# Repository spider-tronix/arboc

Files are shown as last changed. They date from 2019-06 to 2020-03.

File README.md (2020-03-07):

# Arboc
# Abstract:

Researches about underwater propulsion mainly illustrate the use of propellers or thrusters to propel a robot in an underwater environment whereas most of the aquatic animals change their body shape in order to navigate.The shape-change generating propulsion force makes them move forward or backward effectively.The underwater snake-like robot is a kind of bionic robot which changes its body shape to navigate in underwater environment.The aim of the project is to understand the dynamics of underwater robots in general and the effect of lift, drag and hydrodynamic coefficients on them and to simulate, validate and develop a snake-like robot which is robust enough to carry out underwater exploratory tasks.

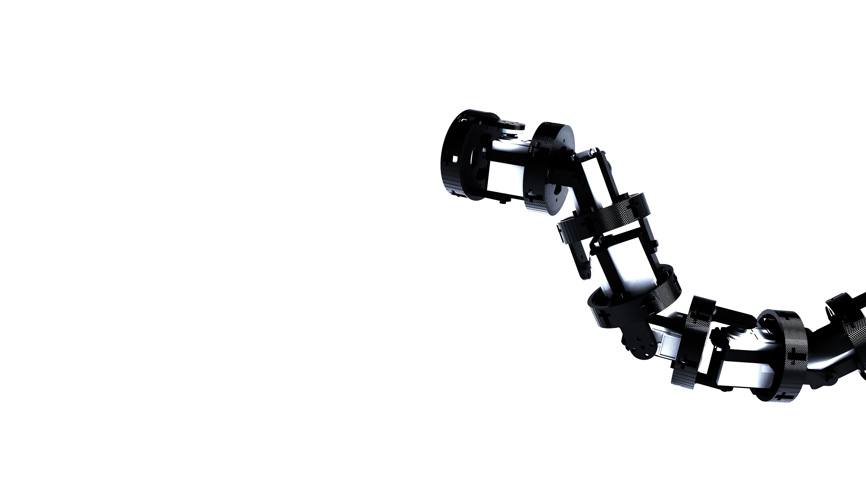
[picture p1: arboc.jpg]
arboc


# Scope of research ::

arboc

  •	Comprehensive simulation and validation of underwater bionic robots using ROS and gazebo.

  •	Goal based locomotion and object tracking for underwater exploratory robots using deep reinforcement learning.

# Paper Submission:
  •	ICCAR
  
# Team:

  • Aditya Singh [https://github.com/adityasingh3007]
  
  • Jack Samuel S [https://github.com/jaxxstar] 
  
  • Manu Aatitya [https://github.com/manuaatitya]  
  
  • Senthur Raj [https://github.com/imsenthur]

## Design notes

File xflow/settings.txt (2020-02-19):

Project Tree:

Create geometry:
__Direction: x:0.0 y:0.0 z:1.0
__Num radial segments: 20
__Num longit. segments: 16

Environment:
__Engine:
____Kernel: 2d

__Environment:
____Wind tunnel*: Dimensions: ()m
____Boundary conditions: Velocity: X: ()m.s-1

Materials:
(For a cylinder of diameter* 0.4m)

__Materials: Material 1
____Reference density*: 1kg.m-3
____Dynamic viscosity*: 0.001Pa.s
____Reynolds number*: 4000
____Velocity of fluid: 10m.s-1

Simulation:
__Time:
____Simulation time: 2s
__Resolution:
____Resolved scale: 0.04m

------------------------------------
------------- R U N ----------------
------------------------------------

Post processing:

Refinement method:
__Adaptive refinement:
____Target resolved resolution*: 0.02m
____Wake resolution*: 0.02m

*Subjected to change

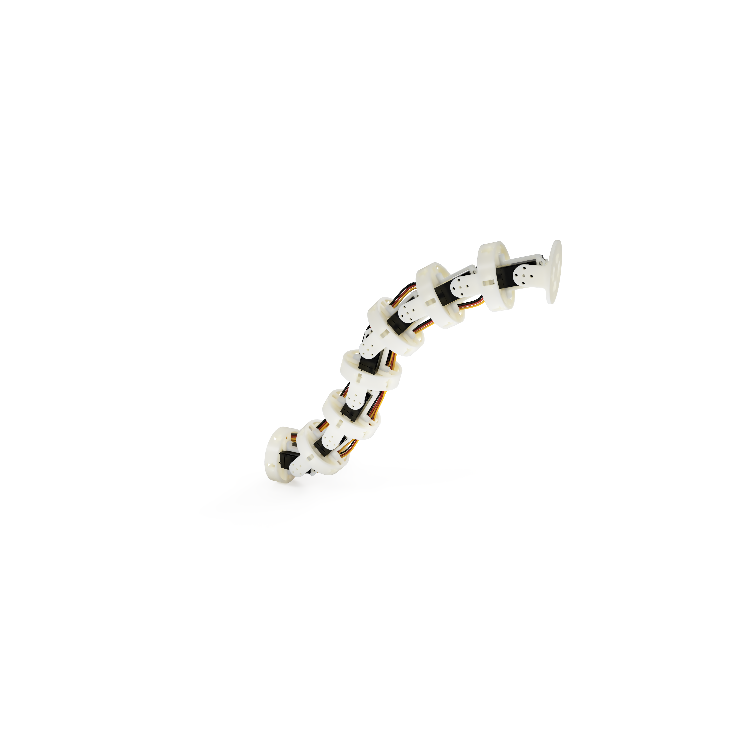
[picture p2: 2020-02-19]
design/Render/iso.png

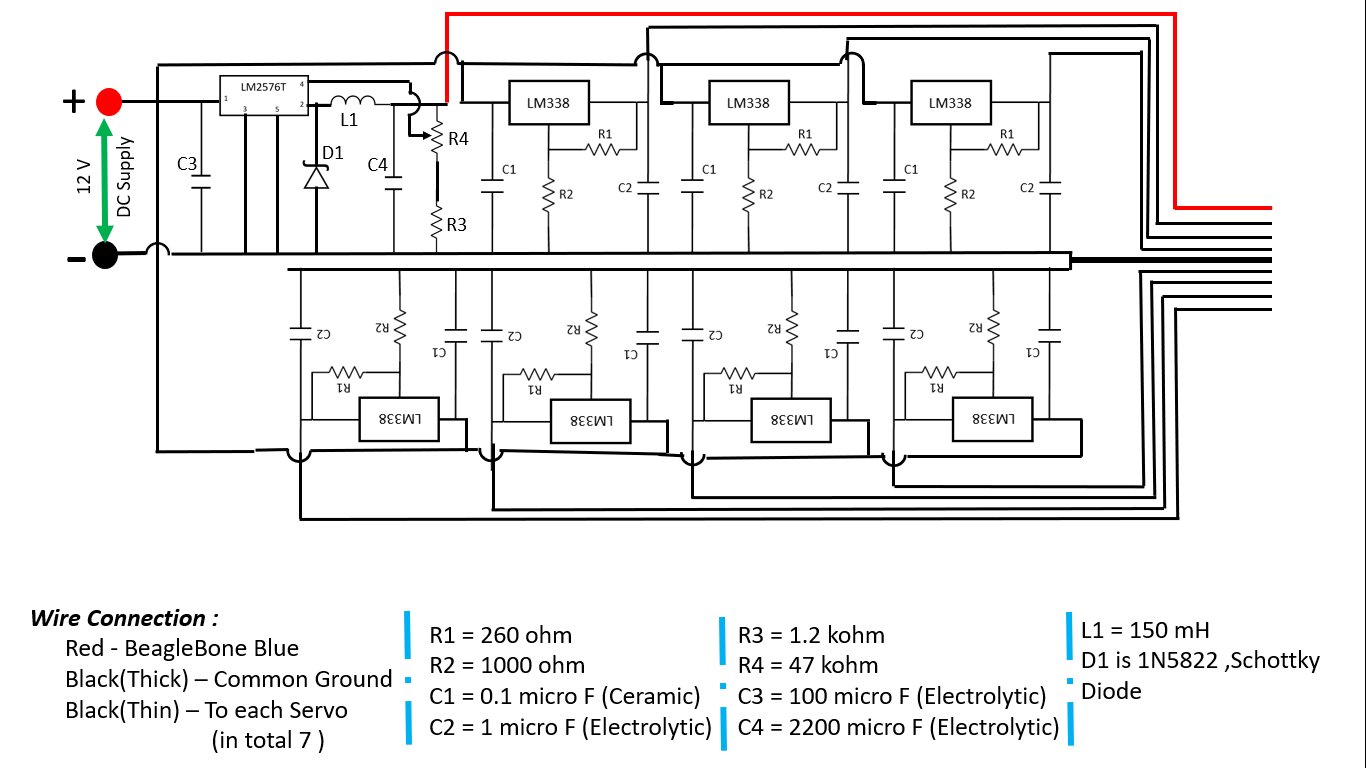
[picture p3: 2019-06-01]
powerSupplyDesign/circuit.png

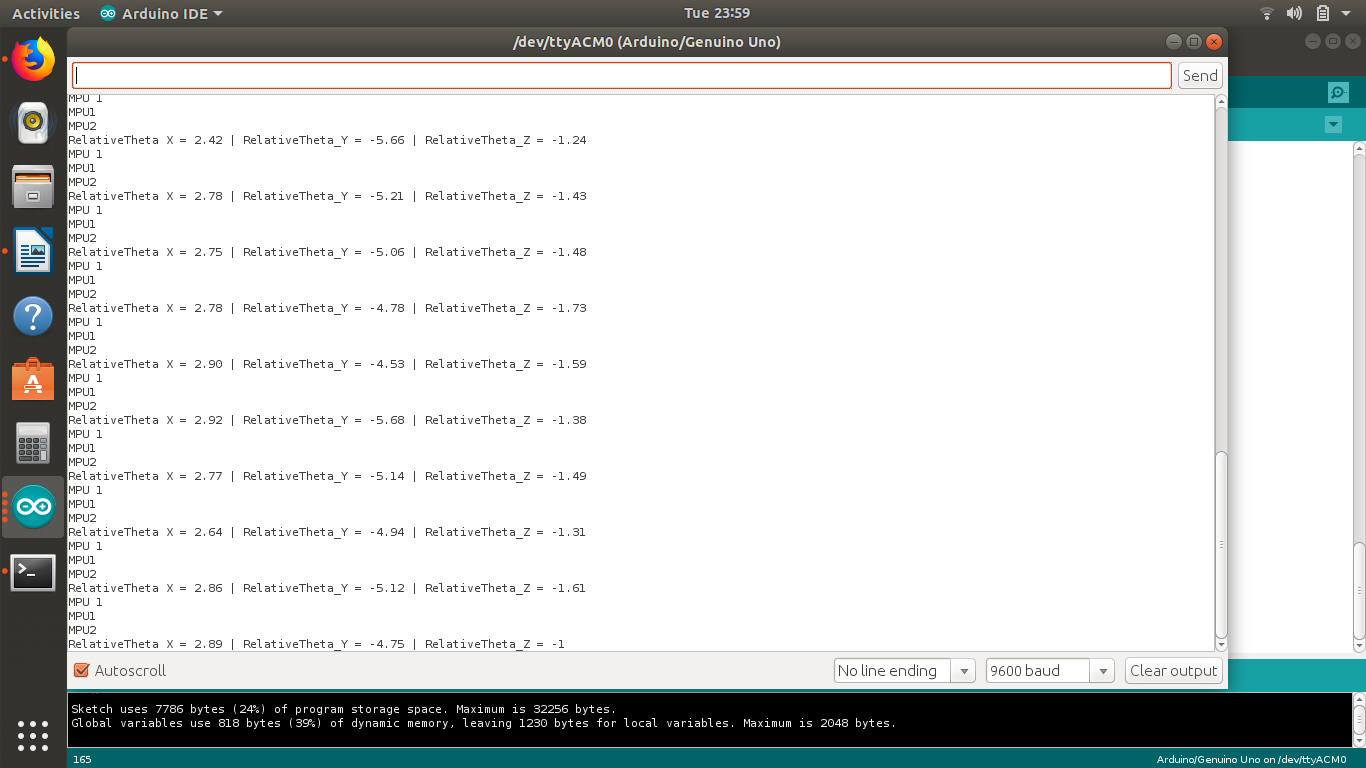
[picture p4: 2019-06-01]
control/IMU/Relative_angle.png

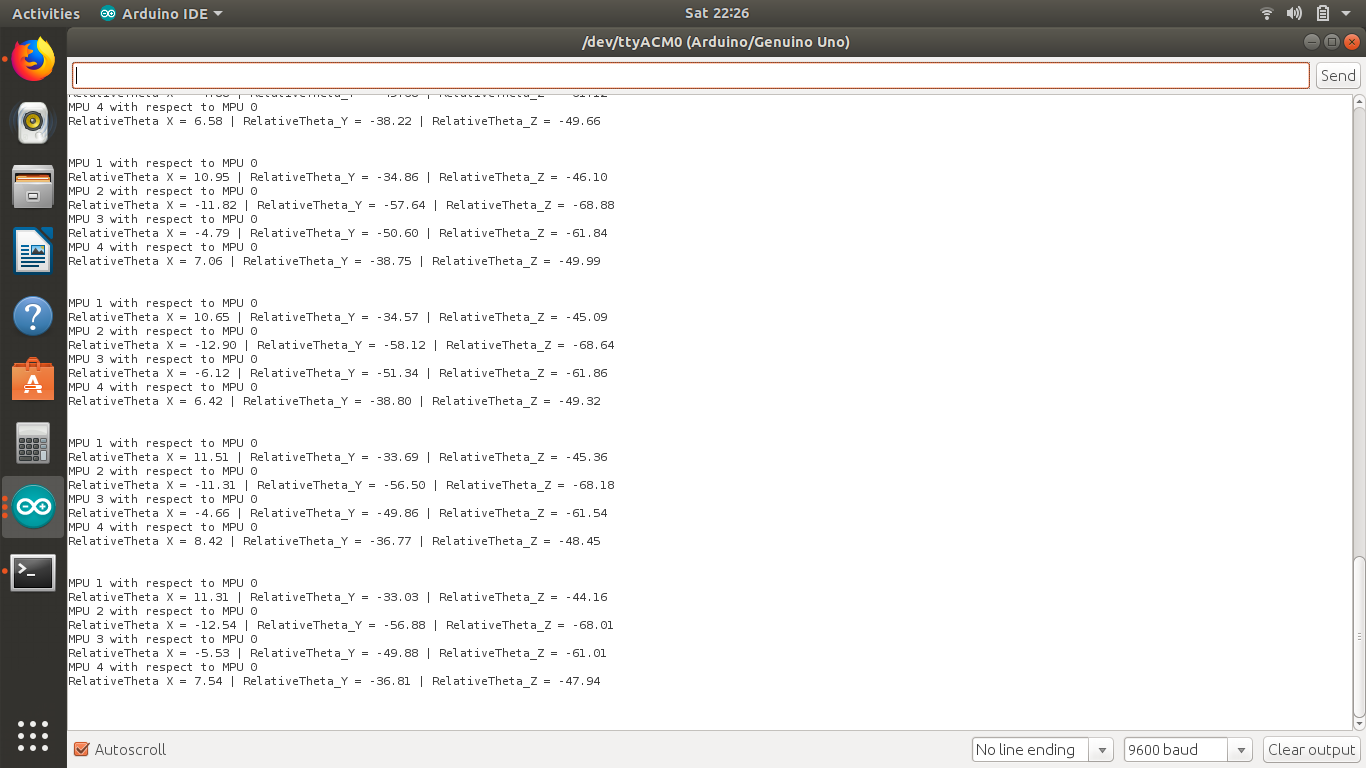
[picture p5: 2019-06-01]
control/IMU/relative_angle_5imu.png

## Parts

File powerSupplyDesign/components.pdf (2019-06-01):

LIST OF CIRCUIT ELEMENTS

S No. | Name | Range / Value | Qty
1. | LM338T Voltage Regulator (TO-220) | 1.2V to 32V, 5A | 10
2. | LM2576T Adj Regulator (TO-220) | | 03
3. | Resistor | 220 ohm,¼ watt 1 kohm,¼ watt 1.2 kohm,¼ watt | 10 10 03
4. | Rheostat | 47 kohm,¼ watt | 02
5. | Capacitor (Electrolytic) | 1 uF, 20 V 100 uF, 30 V 2200 uF, 20 V | 10 03 03
6. | Capacitor (Ceramic) | 0.1 uF, 30V | 10
7. | Inductor (CD74R) | 150 mH | 03
8. | Schottky Diode (1N5822) | 10-20V | 03
9. | Heat sinks | 1k/watt thermal resistance 30Watts disspation capacity | 10
10 | Thermal grease

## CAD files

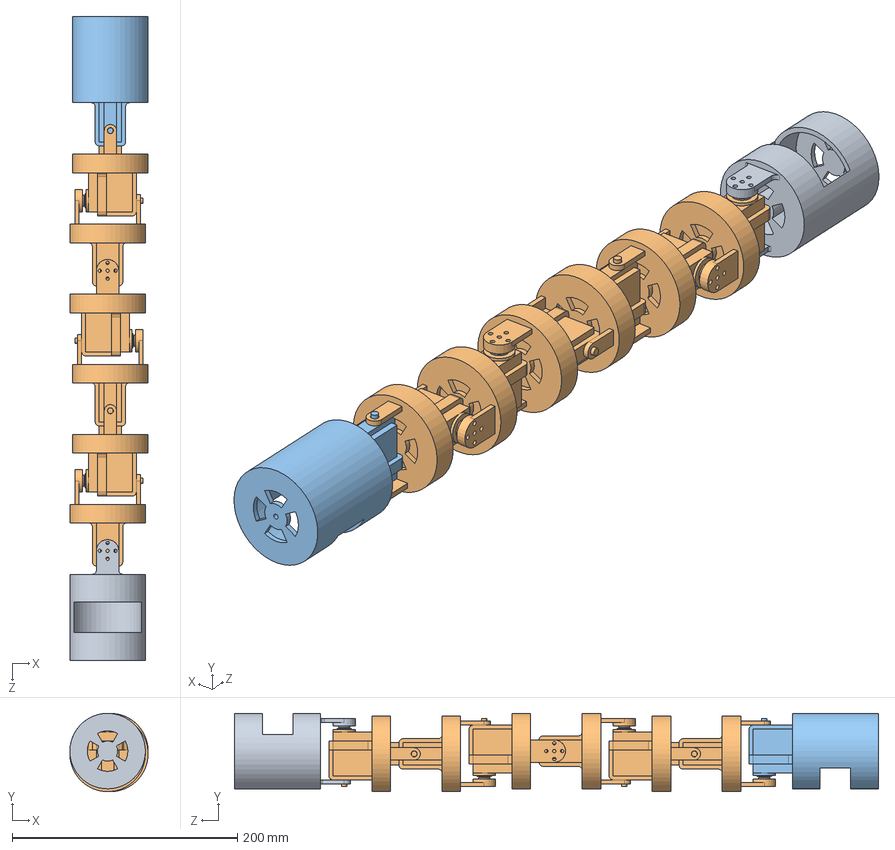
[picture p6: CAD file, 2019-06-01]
mechanicalDesign/solidworks/mainAssembly/arboc.SLDASM
69.5 x 69.5 x 571.3 mm
head
module x 6
tail

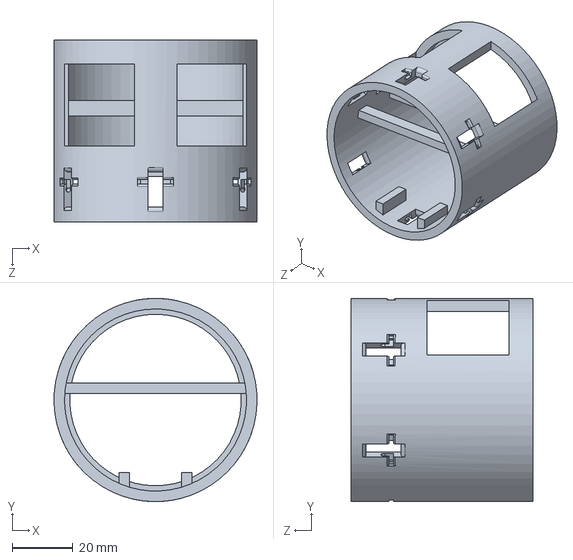
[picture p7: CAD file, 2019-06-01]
mechanicalDesign/solidworks/subAssembly/headNew.SLDASM
66.9 x 67.0 x 60.0 mm

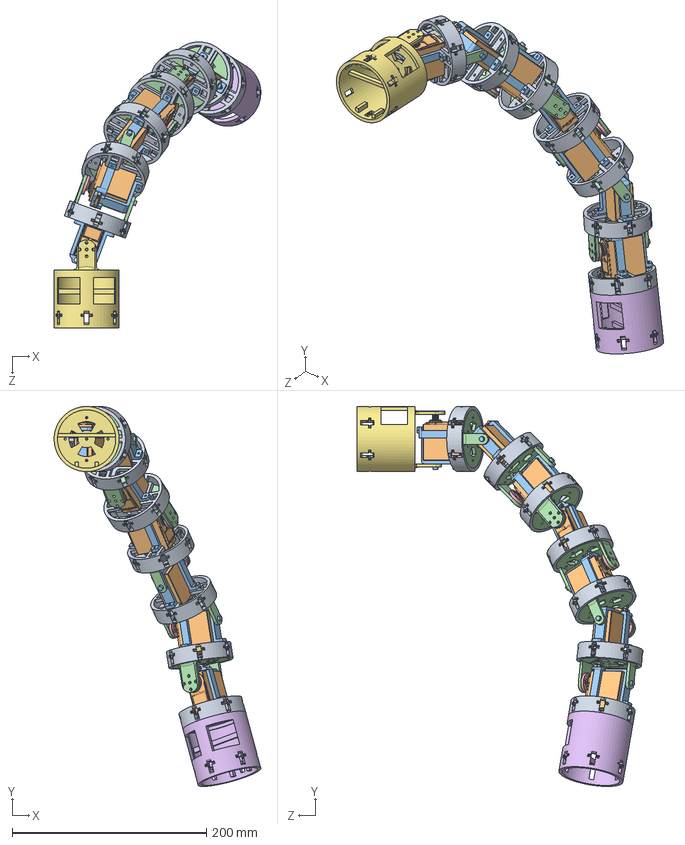
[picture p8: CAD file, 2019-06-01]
mechanicalDesign/solidworks/mainAssembly/arbocImprov.SLDASM
212.8 x 391.1 x 294.4 mm
LowerBracket x 7
Servo x 7
MiddleBracket x 7
UpperBracket x 6
Metalhorn x 6
Tail
Newhead

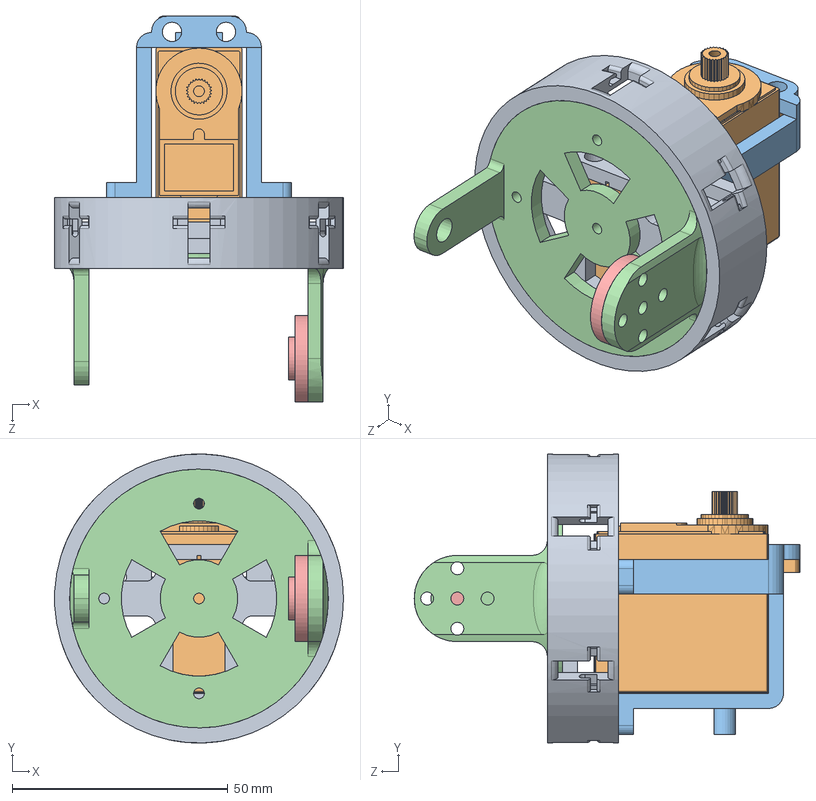
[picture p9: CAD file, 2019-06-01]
mechanicalDesign/solidworks/subAssembly/module.SLDASM
67.0 x 67.0 x 89.4 mm
LowerBracket
Servo
MiddleBracket
UpperBracket
Metalhorn

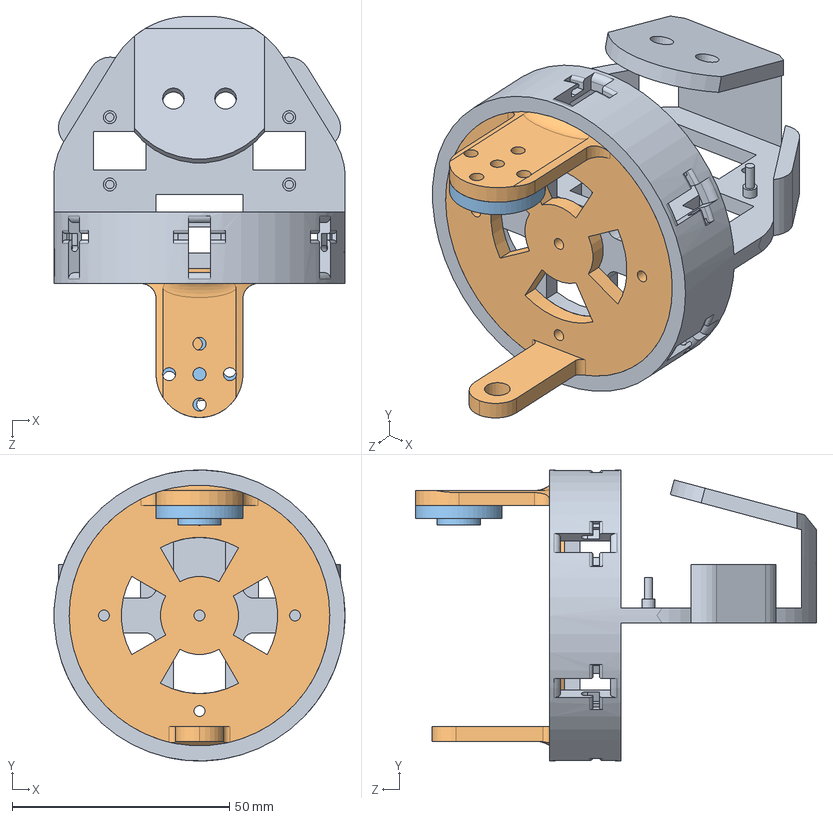
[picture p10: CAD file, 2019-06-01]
mechanicalDesign/solidworks/subAssembly/head.SLDASM
67.0 x 67.0 x 92.4 mm
Head
UpperBracket
Metalhorn

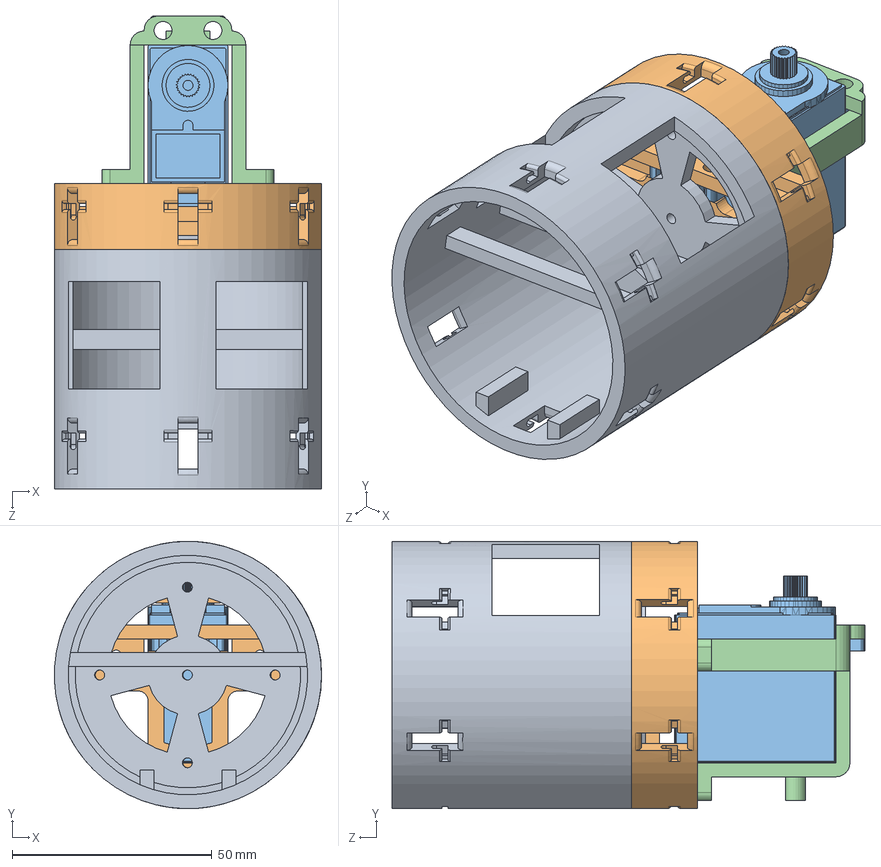
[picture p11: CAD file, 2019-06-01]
mechanicalDesign/solidworks/subAssembly/tail.SLDASM
67.0 x 67.0 x 118.5 mm
Tail
LowerBracket
Servo
MiddleBracket

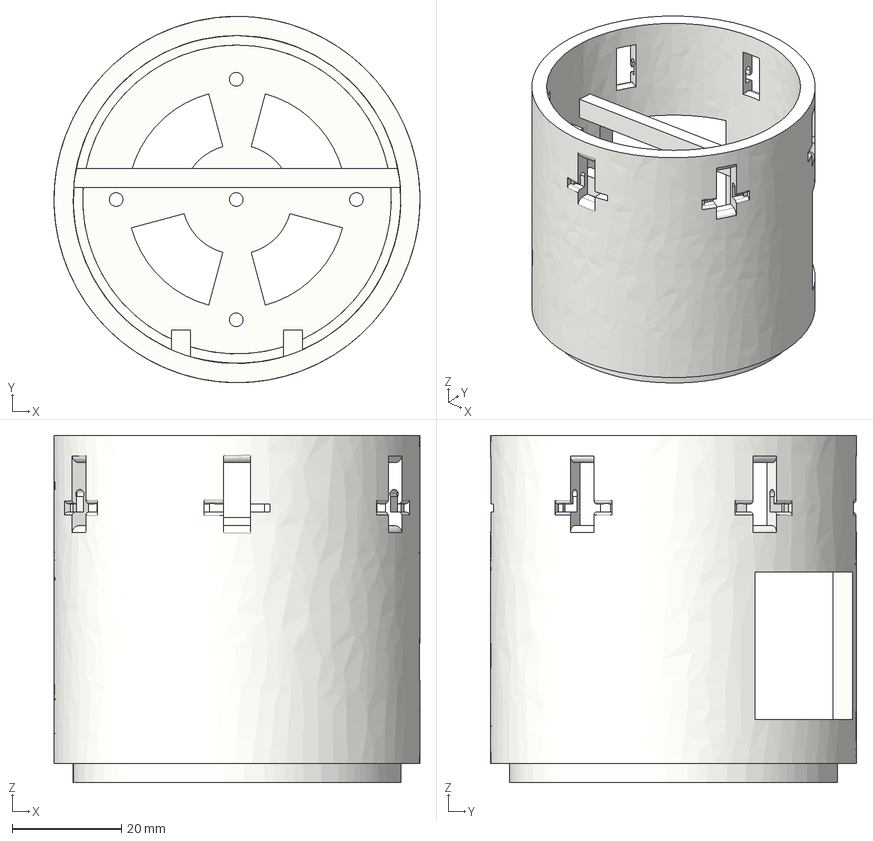
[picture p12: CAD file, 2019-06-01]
mechanicalDesign/3DprintedParts/type5.step
66.9 x 67.0 x 63.5 mm

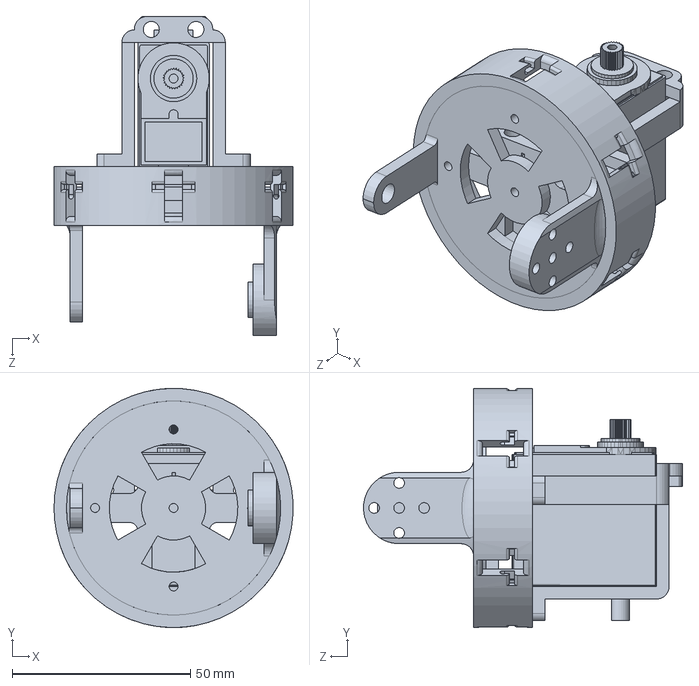
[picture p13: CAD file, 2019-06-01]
mechanicalDesign/solidworks/iges/link.SLDPRT
67.0 x 67.0 x 89.4 mm

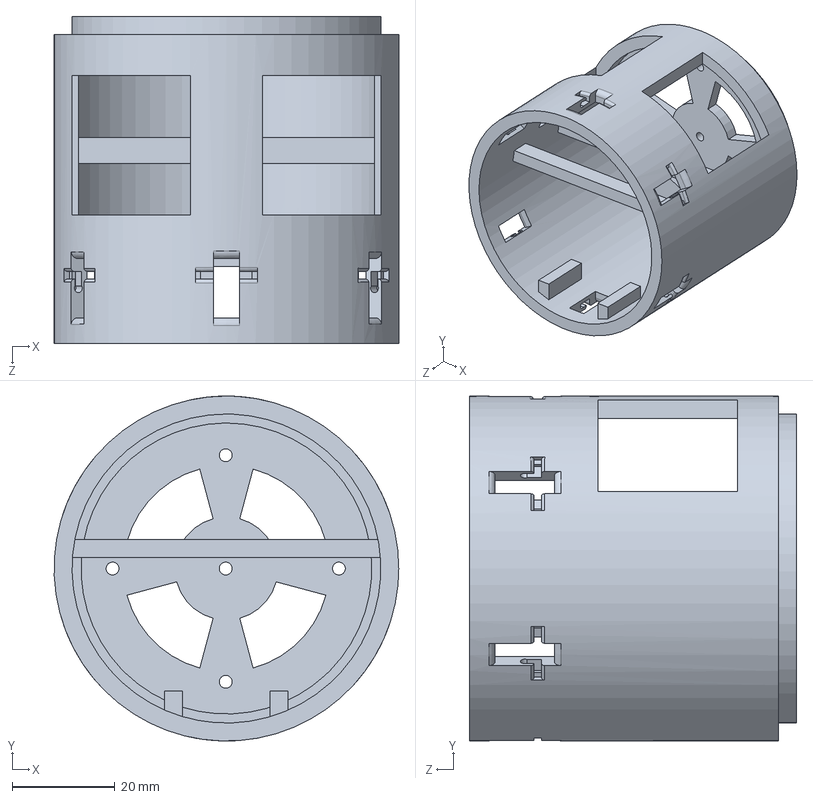
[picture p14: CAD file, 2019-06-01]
mechanicalDesign/solidworks/sldprt/tailNew.SLDPRT
66.9 x 67.0 x 63.5 mm

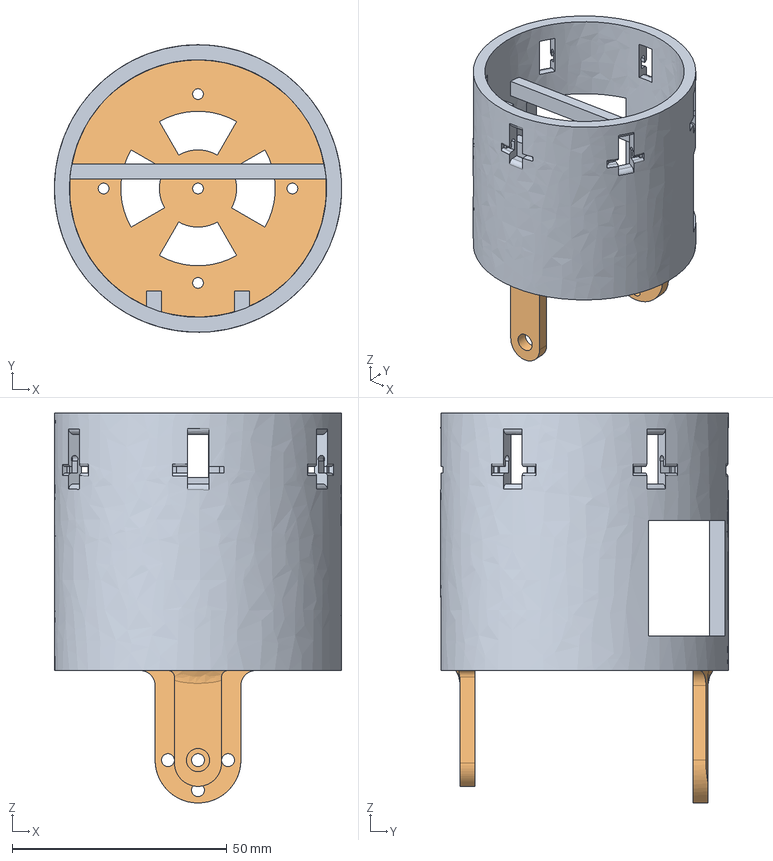
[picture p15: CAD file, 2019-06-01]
mechanicalDesign/solidworks/step/newHead.step
66.9 x 67.0 x 90.9 mm
Tail v1
UpperBracket v1

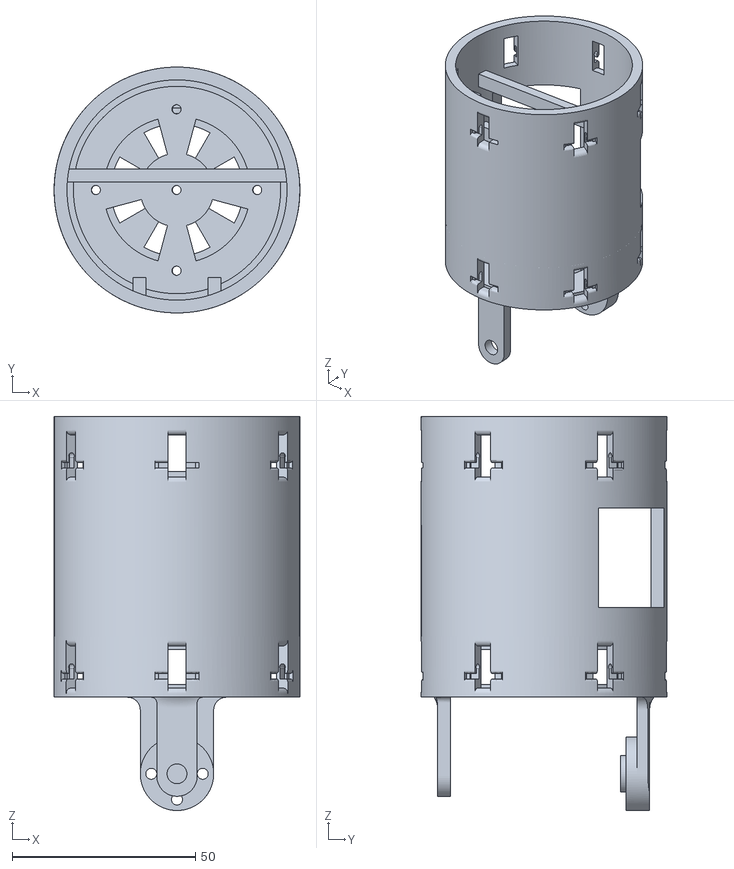
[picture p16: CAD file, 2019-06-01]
simulationExports/vrep/stl/headVisible.stl
67.0 x 67.0 x 107.4

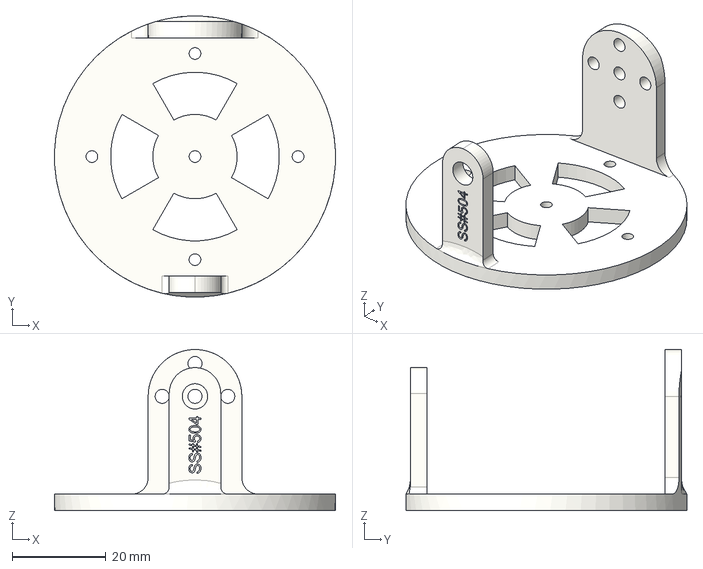
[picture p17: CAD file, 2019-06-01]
mechanicalDesign/3DprintedParts/type3.step
60.0 x 60.0 x 34.4 mm

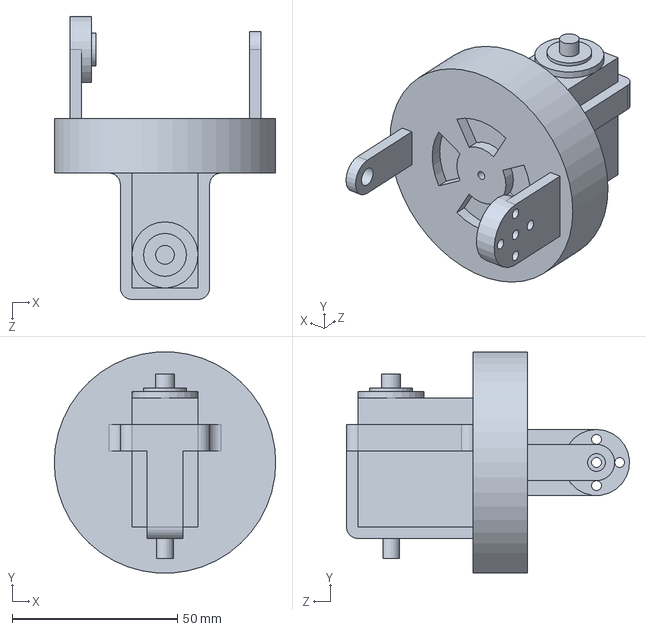
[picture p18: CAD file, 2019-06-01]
mechanicalDesign/solidworks/sldprt/module.SLDPRT
67.0 x 66.8 x 85.6 mm

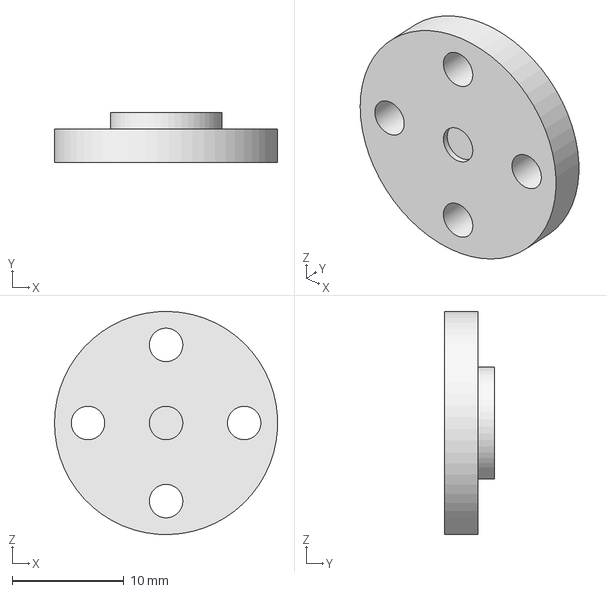
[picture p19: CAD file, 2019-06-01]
mechanicalDesign/solidworks/step/metalHorn.step
20.0 x 4.50 x 20.0 mm

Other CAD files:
simulationExports/gazebo/stl/moduleLeft.stl
mechanicalDesign/solidworks/iges/headLink.SLDPRT
simulationExports/gazebo/stl/end.stl
simulationExports/vrep/stl/tailVisible.stl
mechanicalDesign/3DprintedParts/type1.step
mechanicalDesign/3DprintedParts/type1.stl
mechanicalDesign/3DprintedParts/type2.step
mechanicalDesign/3DprintedParts/type2.stl
mechanicalDesign/3DprintedParts/type3.stl
mechanicalDesign/3DprintedParts/type4.step
mechanicalDesign/3DprintedParts/type4.stl
mechanicalDesign/3DprintedParts/type5.stl
mechanicalDesign/3DprintedParts/type6.step
mechanicalDesign/3DprintedParts/type6.stl
mechanicalDesign/fusion360/NewDesignexport.f3d
mechanicalDesign/solidworks/iges/tailLink.SLDPRT
mechanicalDesign/solidworks/sldprt/head.SLDPRT
mechanicalDesign/solidworks/sldprt/headMod.SLDPRT
mechanicalDesign/solidworks/sldprt/headNew.SLDPRT
mechanicalDesign/solidworks/sldprt/lowerBracket.SLDPRT
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

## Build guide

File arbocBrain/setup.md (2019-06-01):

# arbocBrain

>  With an aim of tasking the robot with gait generation and goal based locomotion, we have buffed up a Beaglebone Blue with numerous packages that aid in both server-client communication and client-side computation.

## Installation

BeagleBone® Blue is an all-in-one Linux-based computer for robotics which comes preloaded with a Debian distribution (Debian jessie) which can be upgraded to a latest firmware from https://beagleboard.org/latest-images. Since most of the computation and processing is done with ROS on the server, it becomes crucial that the client has an active installation of ROS with all the necessary packages. Though ROS distros are available for Debian, its a bit finicky when it comes to installation and support. So we flashed the Beaglebone Blue with a custom ubuntu image (ubuntu 16.04) which we found at https://jh.app.box.com/v/530-707-Dropbox, which is a pre-built image courtesy of Robert Nelson, Jeff O’Brian, and louis whitcomb that comes with ROS Kinetic pre-installed. The entire process has been explained further with much detail below.

#### Expanding file system partition:
The image mentioned above is a 8GB ubuntu-16.04 image which converts the attached SD card to a file system of 8GB capacity irrespective of its native capacity. Make sure to expand the file system partition before proceeding further.

Refer to https://dev.iachieved.it/iachievedit/expanding-your-beaglebone-microsd-filesystem/.

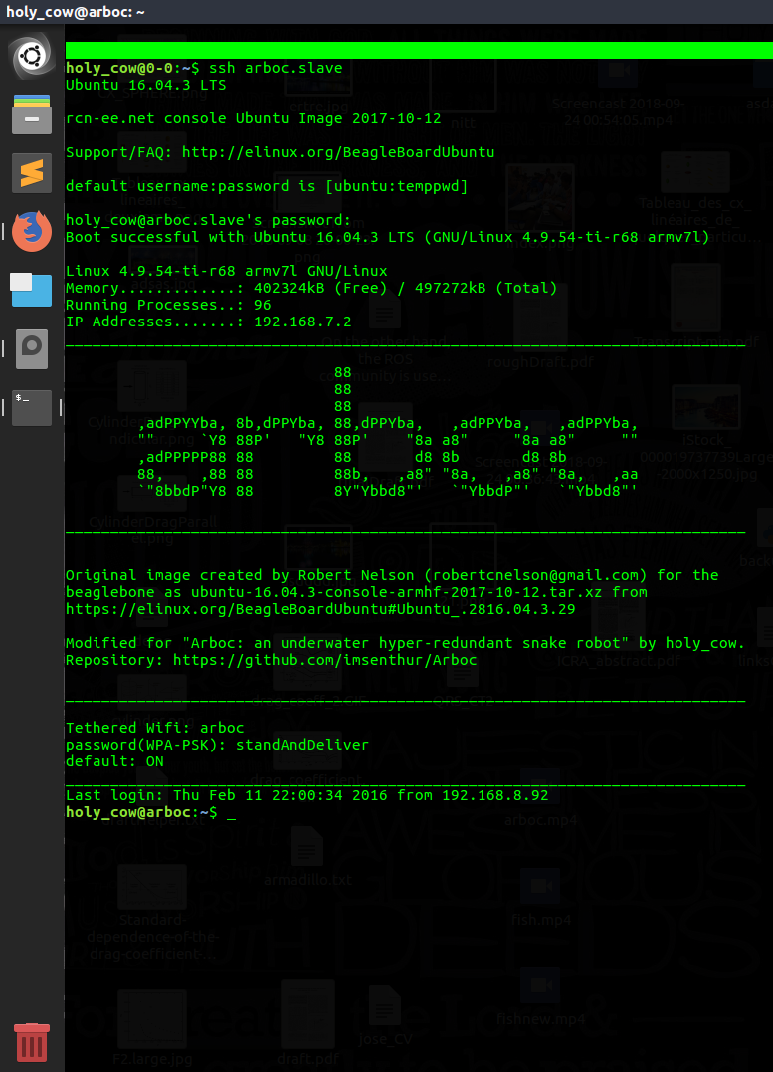
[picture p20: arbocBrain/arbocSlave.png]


#### ROS network configuration requirements:
ROS has certain requirements for the network configuration:

- There must be complete, bi-directional connectivity between all pairs of machines, on all ports. 
- Each machine must advertise itself by a name that all other machines can resolve. 

To check basic connectivity, ping each machine from itself,
```html
  ~ssh arboc.slave
  ~ping arboc.slave
```
and also ping between machines,
```html
  ~ssh arboc.slave
  ~ping arboc.master
```
you should see something like this,
```html
  PING arboc.master: 56 data bytes
  64 bytes from 192.168.1.1: icmp_seq=0 ttl=63 time=1.868 ms
  64 bytes from 192.168.1.1: icmp_seq=1 ttl=63 time=2.677 ms
  64 bytes from 192.168.1.1: icmp_seq=2 ttl=63 time=1.659 ms
```
#### ROS network setup:
Set your ROS environment variables on both master (server) and the slave (client). You can perform this by editing your bashrc script to include "ROS_MASTER_URI" and "ROS_HOSTNAME" which are crucial when it comes to networking with ROS.
```html
  ~sudo subl ~/.bashrc
```
and add these lines to the end of script,
```html
  export ROS_MASTER_URI=http://arboc.master:11311
  export ROS_HOSTNAME=arboc.master
```
and source it.
```html
  ~source ~/.bashrc
```
Make sure you perform the above mentioned steps on the Beaglebone too (but with ROS_HOSTNAME=arboc.slave).
Here "arboc.master" and "arboc.slave" corresponds to the IP address of the master(PC/server) and slave(Beaglebone Blue) respectively. You can add these entries to your "/etc/hosts" to save the hassle of typing the entire IP address everytime you login into your device and it also enables multiple devices to identify each other. The hosts file tells each device how to convert specific names into an IP address.

Once the environment variables are set you must be able to get the following output, 
For the master (PC/server),
```html
  ~echo $ROS_MASTER_URI
  http://arboc.master:11311
  ~echo $ROS_HOSTNAME
  arboc.master
```
and for the slave (Beaglebone Blue),

```html
  ~echo $ROS_MASTER_URI
  http://arboc.master:11311
  ~echo $ROS_HOSTNAME
  arboc.slave
```
We are assuming that "roscore" is being run only on the master and the slave subscribes to multiple topics that are being published. 

#### Time synchronization:
You may have a discrepancy in system times between the master and slave. You can check it from the slave(Beaglebone Blue) using,
```html
  ~ssh arboc.slave
  ~ntpdate -q arboc.master
```
If there is a discrepancy, install chrony and ntpdate by running,
```html
  sudo apt-get install chrony ntpdate
```
Once the installation is successful, make sure you disable "automatic time update" so that the system time doesnot get changed during execution. In order to do disable it, run the following command,
```html
  timedatectl set-ntp false
```
Then configure chrony to query the server's system time, and slowly get the time in-sync. In order to do that, just open the file "/etc/chrony/chrony.conf" in your text editor and add these lines to it,
```html
  server arboc.master minpoll 0 maxpoll 5 maxdelay .05
```
Finally, make sure that the timezones between the master and slave are consistent. If they're not the same then you can change it using,
```html
  sudo timedatectl set-timezone Asia/Kolkata
```
Note that the above command changes the timezone to IST(Indian Standard Time).

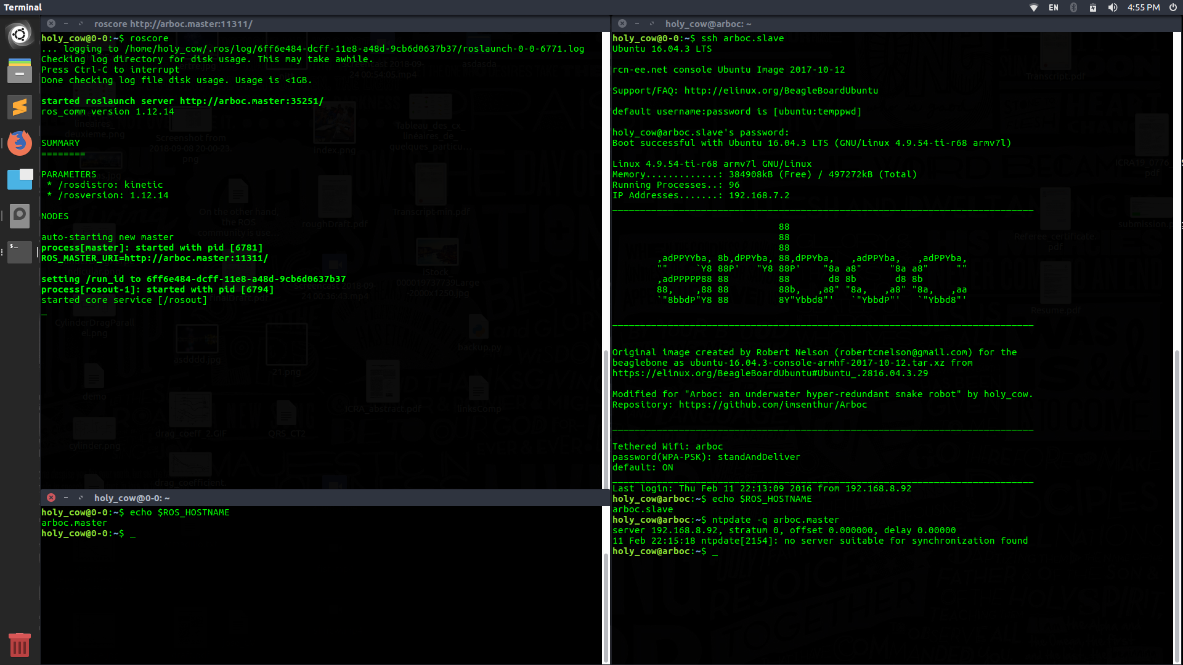
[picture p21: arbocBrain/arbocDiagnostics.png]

#### Diagnostics:
To start with, query the current time offset by running,
```html
  ~ssh arboc.slave
  ~sudo ntpdate -q arboc.master
```
If they are at perfect sync, you're good to go.
Start the roscore on master (PC/server) and run a publisher node,
```html
  ~roscore
  ~rostopic pub -r 10 /hello std_msgs/String "Hello"
```
Now ssh onto your slave and list the topics being published,
```html
  ~ssh arboc.slave
  ~rostopic list
```
You must be able to see a list of all the topics that are being published,
```html
  /hello
  /rosout
  ...
```
Now try echoing the published topic,
```html
  ~rostopic echo /hello
```
you should be getting "hello"s on the output terminal at a rate of 10Hz.
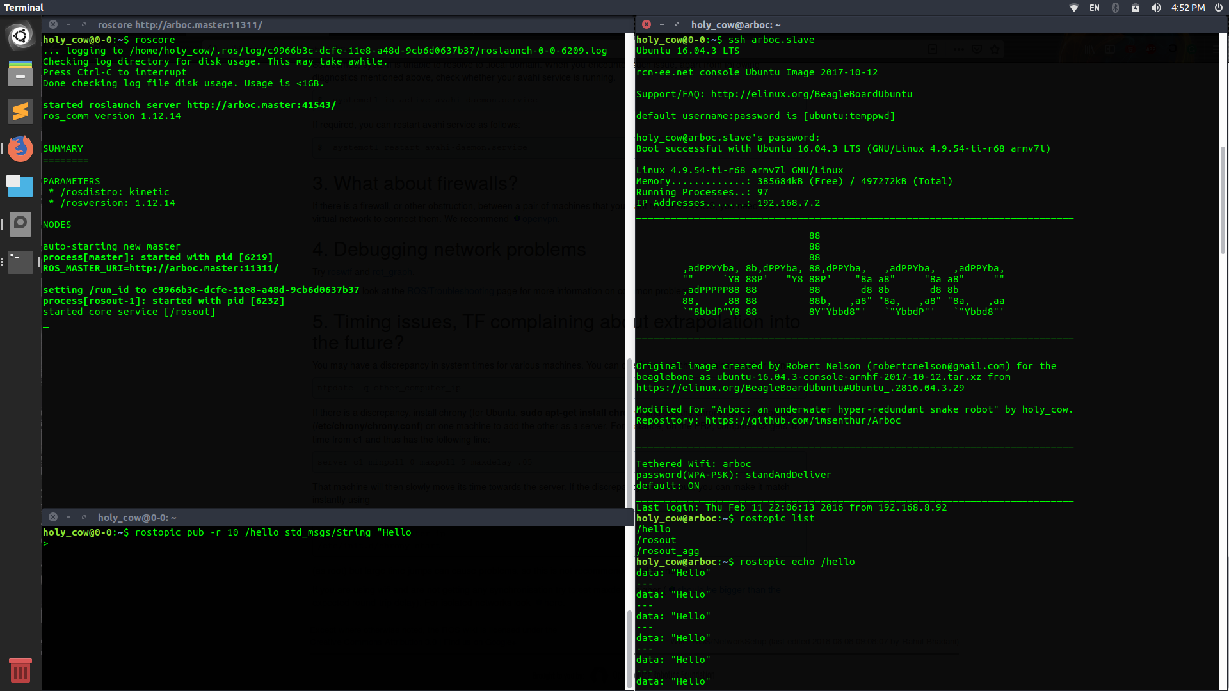
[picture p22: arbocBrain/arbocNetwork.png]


[Back To The Top](#arbocBrain)

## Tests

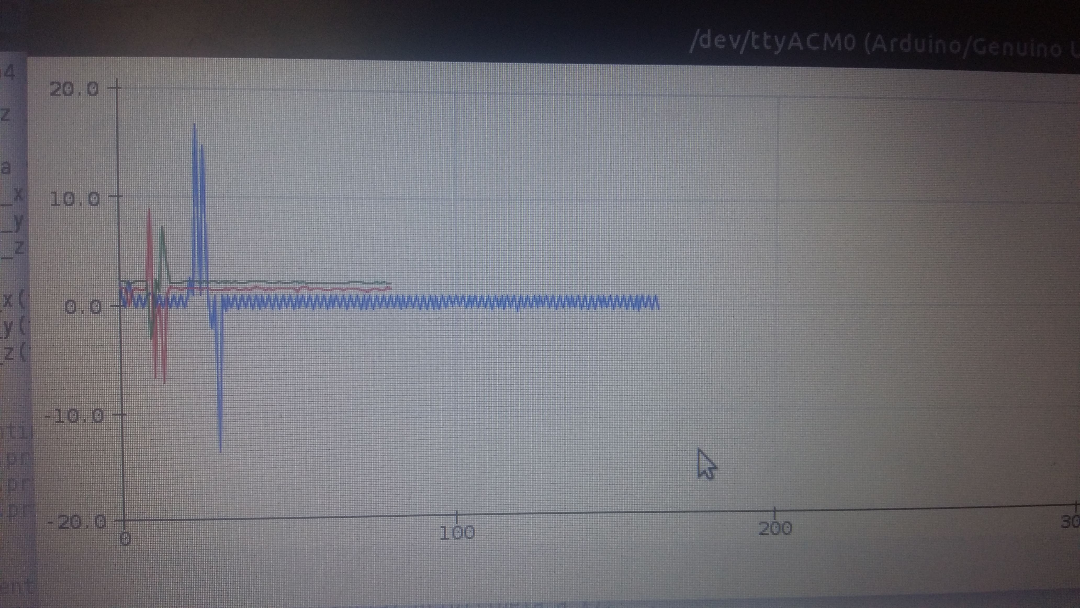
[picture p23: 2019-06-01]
control/IMU/complimentary_result.jpg

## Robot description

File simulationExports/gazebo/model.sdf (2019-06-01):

<?xml version="1.0"?>
<sdf version="1.5">
	<model name="snake">
		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
		<link name="base_link">
			<pose>0 0 0.03825 0 0 0</pose>
			<inertial>
				<mass>0.095875</mass>
				<inertia>
					<ixx>0.00021427111</ixx>
					<iyy>0.00021427111</iyy>
					<izz>0.000054</izz>
					<ixy>0</ixy>
					<ixz>0</ixz>
					<iyz>0</iyz>
				</inertia>
			</inertial>
			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
		</link>

		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
		<link name="link_1">
			<pose>0 0 0.1115 0 0 0</pose>
			<inertial>
				<mass>0.093195</mass>
				<inertia>
					<ixx>0.0001378755</ixx>
					<iyy>0.0001378755</iyy>
					<izz>0.000052</izz>
					<ixy>0</ixy>
					<ixz>0</ixz>
					<iyz>0</iyz>
				</inertia>
			</inertial>
			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
		</link>

		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
		<joint type="revolute" name="revolute_1">
			<pose>0 0 -0.0145 0 0 0</pose>
			<parent>base_link</parent>
			<child>link_1</child>
			<axis>
				<xyz>0 1 0</xyz>
				<limit>
					<lower>-1.309</lower>
					<upper>1.309</upper>
				</limit>
			</axis>
		</joint>

		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
		<link name="link_2">
			<pose>0 0 0.1735 0 0 0</pose>
			<inertial>
				<mass>0.093195</mass>
				<inertia>
					<ixx>0.0001378755</ixx>
					<iyy>0.0001378755</iyy>
					<izz>0.000052</izz>
					<ixy>0</ixy>
					<ixz>0</ixz>
					<iyz>0</iyz>
				</inertia>
			</inertial>
			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
		</link>

		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
		<joint type="revolute" name="revolute_2">
			<pose>0 0 -0.0145 0 0 0</pose>
			<parent>link_1</parent>
			<child>link_2</child>
			<axis>
				<xyz>1 0 0</xyz>
				<limit>
					<lower>-1.309</lower>
					<upper>1.309</upper>
				</limit>
			</axis>
		</joint>

		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
		<link name="link_3">
			<pose>0 0 0.2355 0 0 0</pose>
			<inertial>
				<mass>0.093195</mass>
				<inertia>
					<ixx>0.0001378755</ixx>
					<iyy>0.0001378755</iyy>
					<izz>0.000052</izz>
					<ixy>0</ixy>
					<ixz>0</ixz>
					<iyz>0</iyz>
				</inertia>
			</inertial>
			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
		</link>

		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
		<joint type="revolute" name="revolute_3">
			<pose>0 0 -0.0145 0 0 0</pose>
			<parent>link_2</parent>
			<child>link_3</child>
			<axis>
				<xyz>0 1 0</xyz>
				<limit>
					<lower>-1.309</lower>
					<upper>1.309</upper>
				</limit>
			</axis>
		</joint>

		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
		<link name="link_4">
			<pose>0 0 0.2975 0 0 0</pose>
			<inertial>
				<mass>0.093195</mass>
				<inertia>
					<ixx>0.0001378755</ixx>
					<iyy>0.0001378755</iyy>
					<izz>0.000052</izz>
					<ixy>0</ixy>
					<ixz>0</ixz>
					<iyz>0</iyz>
				</inertia>
			</inertial>
			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
		</link>

		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
		<joint type="revolute" name="revolute_4">
			<pose>0 0 -0.0145 0 0 0</pose>
			<parent>link_3</parent>
			<child>link_4</child>
			<axis>
				<xyz>1 0 0</xyz>
				<limit>
					<lower>-1.309</lower>
					<upper>1.309</upper>
				</limit>
			</axis>
		</joint>

		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
		<link name="link_5">
			<pose>0 0 0.3595 0 0 0</pose>
			<inertial>
				<mass>0.093195</mass>
				<inertia>
					<ixx>0.0001378755</ixx>
					<iyy>0.0001378755</iyy>
					<izz>0.000052</izz>
					<ixy>0</ixy>
					<ixz>0</ixz>
					<iyz>0</iyz>
				</inertia>
			</inertial>
			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
		</link>

		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
		<joint type="revolute" name="revolute_5">
			<pose>0 0 -0.0145 0 0 0</pose>
			<parent>link_4</parent>
			<child>link_5</child>
			<axis>
				<xyz>0 1 0</xyz>
				<limit>
					<lower>-1.309</lower>
					<upper>1.309</upper>
				</limit>
			</axis>
		</joint>

		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
		<link name="link_6">
			<pose>0 0 0.4215 0 0 0</pose>
			<inertial>
				<mass>0.093195</mass>
				<inertia>
					<ixx>0.0001378755</ixx>
					<iyy>0.0001378755</iyy>
					<izz>0.000052</izz>
					<ixy>0</ixy>
					<ixz>0</ixz>
					<iyz>0</iyz>
				</inertia>
			</inertial>
			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
		</link>

		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
		<joint type="revolute" name="revolute_6">
			<pose>0 0 -0.0145 0 0 0</pose>
			<parent>link_5</parent>
			<child>link_6</child>
			<axis>
				<xyz>1 0 0</xyz>
				<limit>
					<lower>-1.309</lower>
					<upper>1.309</upper>
				</limit>
			</axis>
		</joint>

		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
		<link name="tail_link">
			<pose>0 0 0.51325 0 0 0</pose>
			<inertial>
				<mass>0.093195</mass>
				<inertia>
					<ixx>0.0001378755</ixx>
					<iyy>0.0001378755</iyy>
					<izz>0.000052</izz>
					<ixy>0</ixy>
					<ixz>0</ixz>
					<iyz>0</iyz>
				</inertia>
			</inertial>
			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
		</link>

		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
		<joint type="revolute" name="tail_revolute">
			<pose>0 0 -0.04375 0 0 0</pose>
			<parent>link_6</parent>
			<child>tail_link</child>
			<axis>
				<xyz>0 1 0</xyz>
				<limit>
					<lower>-1.309</lower>
					<upper>1.309</upper>
				</limit>
			</axis>
		</joint>
	</model>
</sdf>

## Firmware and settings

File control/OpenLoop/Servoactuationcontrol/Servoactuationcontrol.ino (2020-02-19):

#include <Servo.h>
#include <SPI.h>
#include<stdio.h>
#include <avr/io.h>
#include <util/delay.h>
#include <stdlib.h>
#include<avr/interrupt.h>

//PIN MAPPINGS
//132465

/*
 * Serpentine lateral plane:
 * a=0.6*pi
 * b=2*pi
 * c=0
 * 
 *  a=0.75*pi;
    b=3.5*pi;
    c=-0.2*pi;
    num_segments = 5;

          a=1.5*pi;
          b=3*pi;
          c=0*pi;
 */
 /*
  * Rolling gait:
  * a=0.9*pi
  * b=1*pi
  * c=0
  * n=8
  * phase diff += 0.1
  * add pi to switch direction
  */
 
// Define servo objects for the snake segments
Servo s1; 
Servo s2;
Servo s3;
Servo s4; 
Servo s5;
Servo s6;

int gait=1;
int direc=2;
const float pi = 3.141593;
int counter = 0; 
int frequency = 1; 
int startPause = 2000; 
int data[2];
int flag=0;

char tx='1';

float a = 0.5*pi;                                   //Ampli Coeff
float b = 1*pi;                                     //Curve Coeff      
float c = 0;                                        //Turn Coeff
float num_segments = 8;
float gamma=-c/num_segments;
float beta=b/num_segments;
float alpha=a*abs(sin(beta/2));
unsigned long previousMillis = 0;
long interval = 4;

void setup() 
{
  // Attach segments to pins  
   s1.attach(2); //blue left - 1st servo
   s2.attach(3); //black right - 2nd servo
   s3.attach(4); //violet right - 3rd servo 
   s4.attach(5); //black left - 4th servo 
   s5.attach(6); //white left - 5th servo 
   s6.attach(7); //blue right - 6th servo 
 
//Put snake in starting position
   s1.write(90);
   s2.write(90);
   s3.write(90);
   s4.write(90);
   s5.write(90);
   s6.write(90-13); 
 
   delay(startPause);
   previousMillis = millis();
}
void loop() 
{
        //Serpentine gait
          a=0.9*pi;
          b=3*pi;
          c=0*pi;
          num_segments = 8;2
          gamma=-c/num_segments;
          beta=b/num_segments;
          alpha=a*abs(sin(beta/2));
          interval = 3;

          for(counter = 0; counter < 360;) 
          {
            unsigned long currentMillis = millis();
            if (currentMillis - previousMillis >= interval)
            {
              previousMillis = currentMillis;
              s1.write(90 + (alpha*sin(frequency*counter*pi/180+1*beta)+gamma)*180/pi);
              s2.write(90 + (alpha*sin(frequency*counter*pi/180+2*beta+pi/2)+gamma)*180/pi);
              s3.write(90 + (alpha*sin(frequency*counter*pi/180+3*beta)+gamma)*180/pi);
              s4.write(90 + (alpha*sin(frequency*counter*pi/180+4*beta+pi/2)+gamma)*180/pi);
              s5.write(90 + (alpha*sin(frequency*counter*pi/180+5*beta)+gamma)*180/pi);
              s6.write(90 + (alpha*sin(frequency*counter*pi/180+6*beta+pi/2)+gamma)*180/pi);
              counter += 1;
            }       
          }       
}

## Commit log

2019-06-01 Repository organized
    [NewDesignexport.f3d, arboc.SLDASM, arbocImprov.SLDASM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]
2019-09-29 Added servo test
2019-10-08 Initialized flow simulation parameters.
2020-02-20 Added turntable video for pragyan stall
2020-03-07 Added poster for sangam stall
